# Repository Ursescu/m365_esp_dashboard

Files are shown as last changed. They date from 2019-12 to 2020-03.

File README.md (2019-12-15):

# M365 Dashboard replacement

## Description

Replacement for BLE m365 scooter dashboard using ESP32 chip.

## Build

Clone official esp-idf sdk repo and set `IDF_PATH` environment variable
to point it.

```bash
    git clone --recursive https://github.com/espressif/esp-idf.git ~/esp-idf

    cd ~/esp-idf && ./install.sh && . ./export.sh
```

Build app and watch the info using `make`.

```bash
    make flash monitor
```

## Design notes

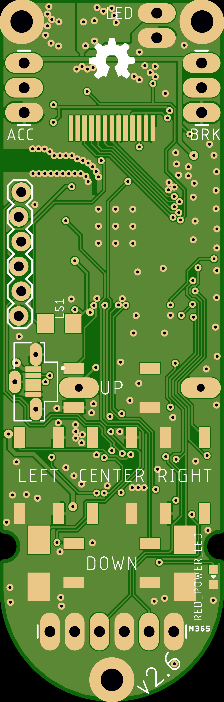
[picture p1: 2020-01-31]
pcb/pcb-render-dashboard-top.png

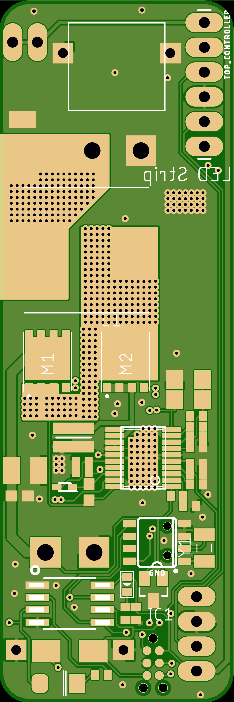
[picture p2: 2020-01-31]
pcb/pcb-render-led-source-top.png

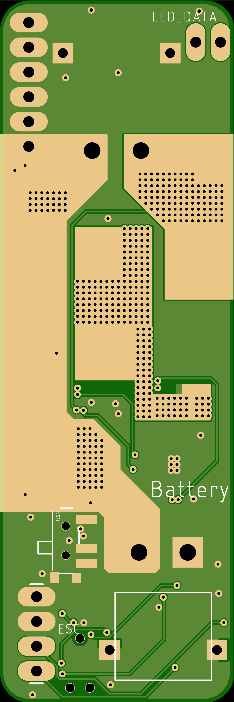
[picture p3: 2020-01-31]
pcb/pcb-render-led-source-bottom.png

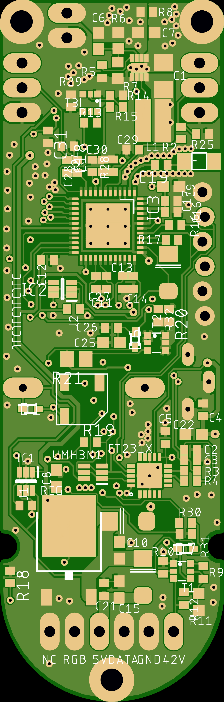
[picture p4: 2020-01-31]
pcb/pcb-render-dashboard-bottom.png

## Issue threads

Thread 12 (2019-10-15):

Add buzzer functionality

Ursescu, 2019-10-15:
Original XIOMI m365 scooter has a buzzer used to indicate alarm status received from ESC/BMS controller.

Add this feature to current implementation in `buzzer.c`.

- [ ]  Advanced beep function with frequency, on-off time and multiple beeps configuration.
- [ ]  Default beep configuration.

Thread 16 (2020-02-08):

Display UX&UI

rontav, 2020-02-08:
Here are some ideas for the display user interface:

### Main screen
| Guest/Eco | Normal | No limits |
| :-------------: | :-------------: |  :-------------: |
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 | 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 | 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

To change the info shown in the dashboard you can press the left or right keys. Proposed dashboard screens:
- summary (images shown above)
- detailed battery info
- max, average and current speed

###  Options screen
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
Is accessed by pressing the down key while on the Main screen. To get back to the Main screen, you have to press the up key while the top most option is highlighted.
Optionally, we could transition between the two screens with a simple translate animation.
The selected option should scroll back and forth to reveal the text.

The icons used are part of FontAwesome.

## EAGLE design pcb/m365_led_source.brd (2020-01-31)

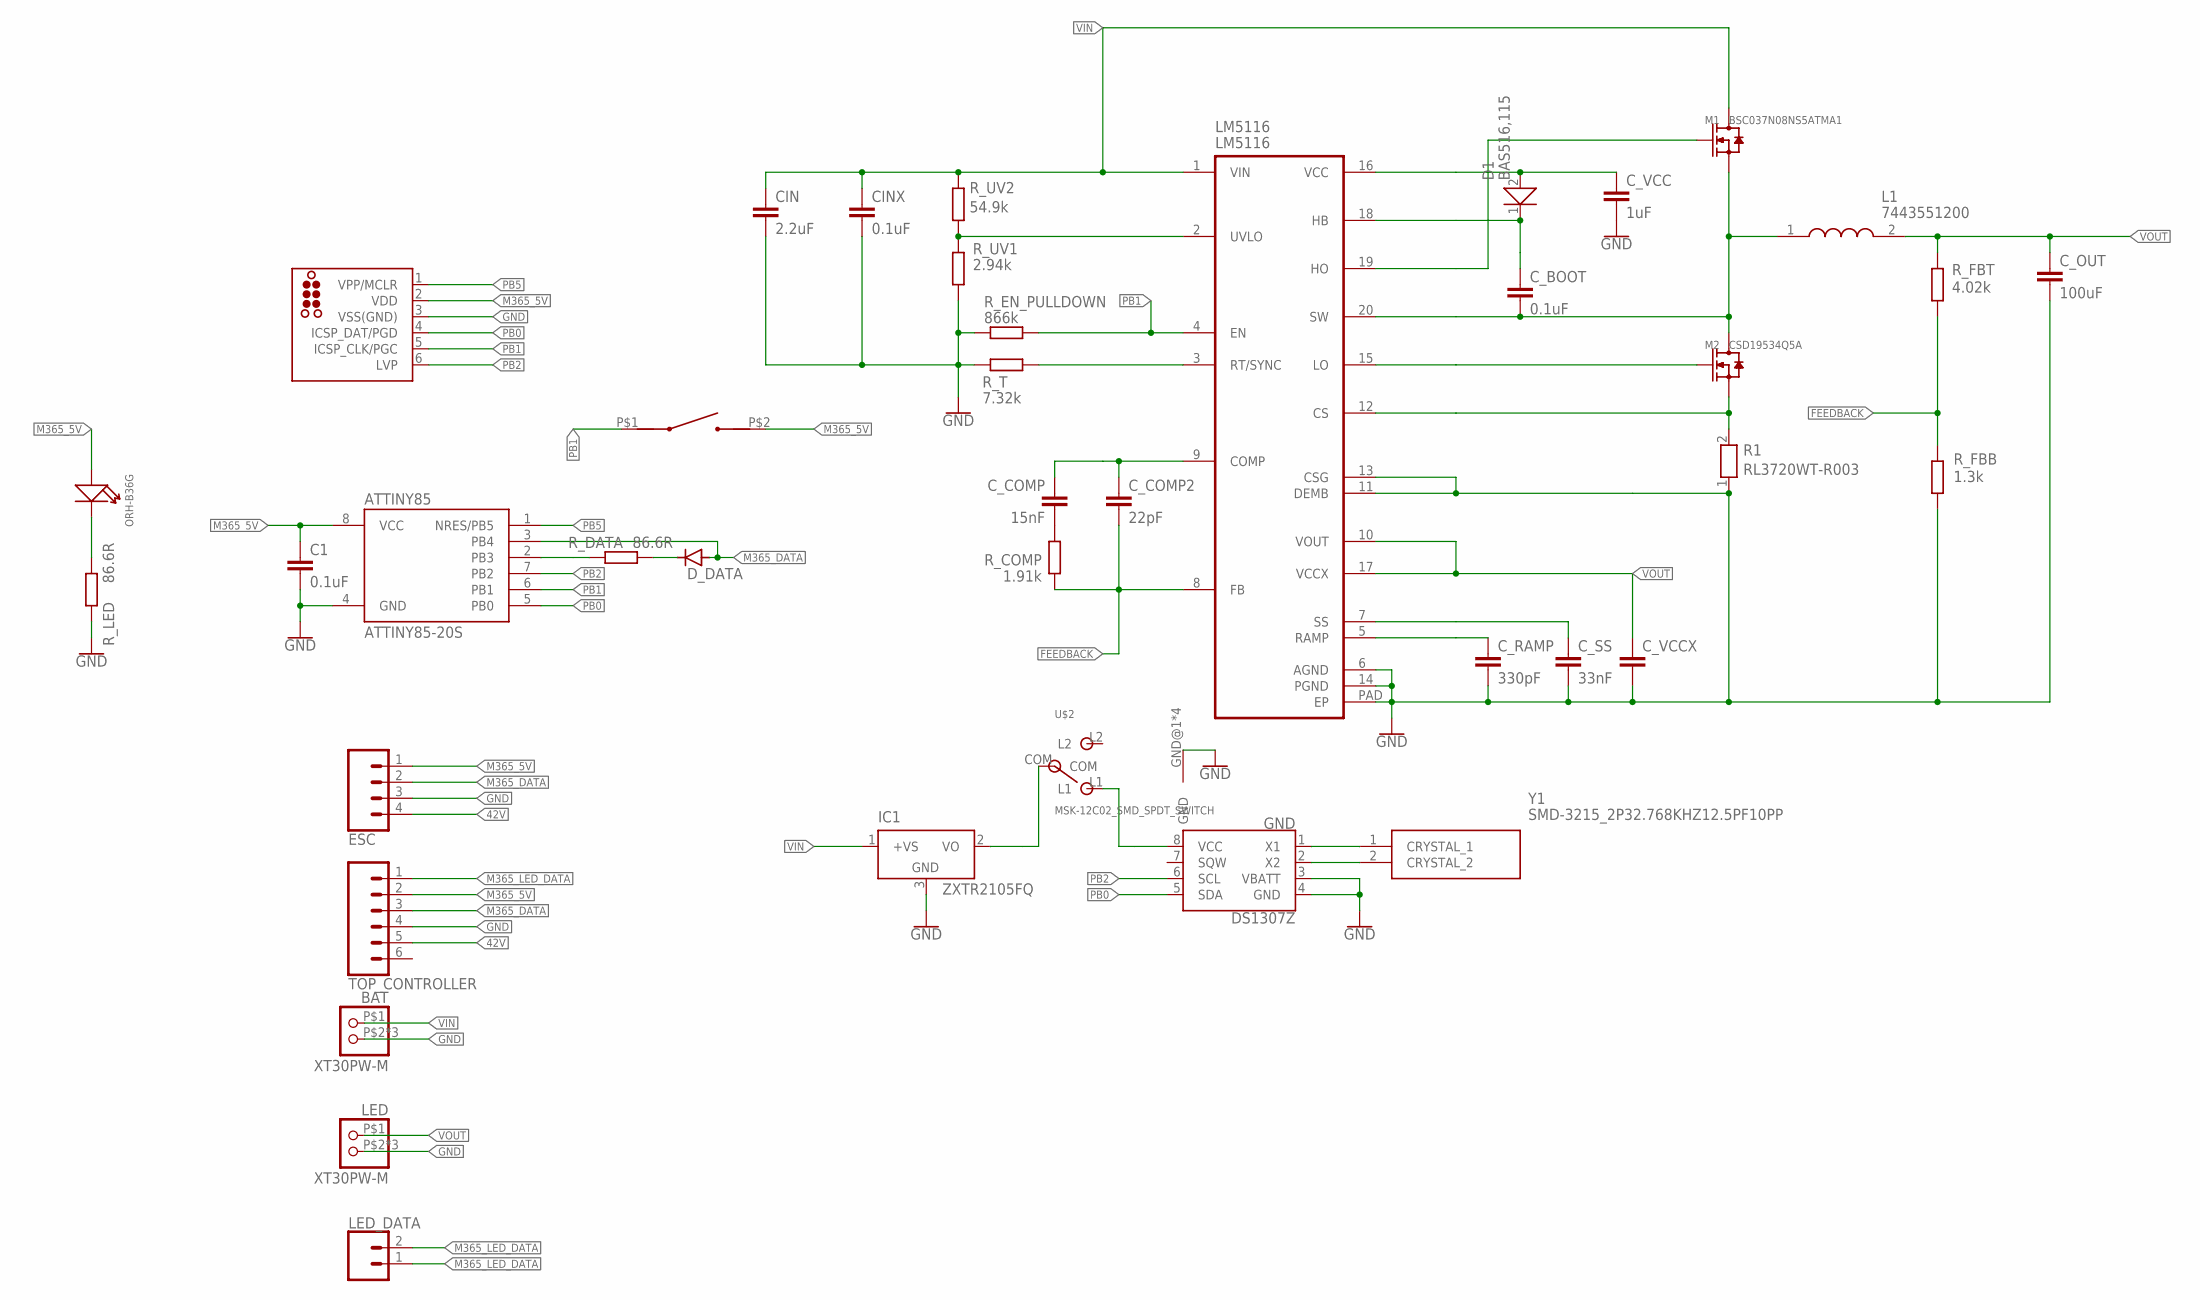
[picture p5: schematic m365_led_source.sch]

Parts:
ATTINY85: ATTINY85-20S; SOIC8_EIAJ_208MIL
BAT: XT30PW-M
C1: 0.1uF; C0402
CIN: 2.2uF; C1210
CINX: 0.1uF; C0603
C_BOOT: 0.1uF; C0603
C_COMP: 15nF; C1005
C_COMP2: 22pF; C0402
C_OUT: 100uF; C1210
C_RAMP: 330pF; C0402
C_SS: 33nF; C0402
C_VCC: 1uF; C0402
C_VCCX: CC0402; C0402
D1: BAS516,115; SOD1608X65N
D_DATA: SMAFJ75A
ESC: CONN_04LONGPADS; 1X04_LONGPADS
GND: DS1307Z; SO08-0.15
IC1: ZXTR2105FQ; SOT23
J2: TC2030-MCP-NL
L1: 7443551200; WE-HCI_1350/136523
LED: XT30PW-M
LED_DATA: CONN_02PTH3; 1X02_LONGPADS
LM5116: LM5116; TSSOP20-PAD
M1: BSC037N08NS5ATMA1; CSD19531Q5AT
M2: CSD19534Q5A; CSD19531Q5AT
R1: RL3720WT-R003; RESC2038X70N
R_COMP: 1.91k; R0402
R_DATA: 86.6R; R0402
R_EN_PULLDOWN: 866k; R0402
R_FBB: 1.3k; R1206
R_FBT: 4.02k; R1206
R_LED: 86.6R; R0402
R_T: 7.32k; R0402
R_UV1: 2.94k; R0402
R_UV2: 54.9k; R0402
TINY_LED: ORH-B36G; LED-0603
TOP_CONTROLLER: CONN_06LONGPADS; 1X06_LONGPADS
U$1: TL3302BF260QJ
U$2: MSK-12C02_SMD_SPDT_SWITCH; MSK-12C02
Y1: SMD-3215_2P32.768KHZ12.5PF10PP; SMD3215_2P32768KHZ125PF10PPM

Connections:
5V_REG: IC1.2 (VO), U$2.COM
42V: ESC.4, TOP_CONTROLLER.5
FEEDBACK: C_COMP2.2, LM5116.8 (FB), R_COMP.1, R_FBB.2, R_FBT.1
GND: ATTINY85.4 (GND), BAT.P$2 (2), BAT.P$3 (2), BAT.P$4 (2), C1.2, CIN.2, CINX.2, C_OUT.2, C_RAMP.2, C_SS.2, C_VCC.2, C_VCCX.2, ESC.3, GND.3 (VBATT), GND.4 (GND), IC1.3 (GND), J2.3 (VSS(GND)), LED.P$2 (2), LED.P$3 (2), LED.P$4 (2), LM5116.6 (AGND), LM5116.11 (DEMB), LM5116.13 (CSG), LM5116.14 (PGND), LM5116.PAD (EP), R1.1, R_EN_PULLDOWN.1, R_FBB.1, R_LED.1, R_T.1, R_UV1.1, TOP_CONTROLLER.4, U$2.GND@1 (GND), U$2.GND@2 (GND), U$2.GND@3 (GND), U$2.GND@4 (GND)
M365_5V: ATTINY85.8 (VCC), C1.1, ESC.1, J2.2 (VDD), TINY_LED.+, TOP_CONTROLLER.2, U$1.P$2
M365_DATA: ATTINY85.3 (PB4), D_DATA.P$2 (ANODE), ESC.2, TOP_CONTROLLER.3
M365_LED_DATA: LED_DATA.1, LED_DATA.2, TOP_CONTROLLER.1
unnamed: C_COMP.2, R_COMP.2
unnamed: LM5116.2 (UVLO), R_UV1.2, R_UV2.1
unnamed: GND.8 (VCC), U$2.L1
unnamed: LM5116.3 (RT/SYNC), R_T.2
unnamed: C_COMP.1, C_COMP2.1, LM5116.9 (COMP)
unnamed: GND.1 (X1), Y1.1 (CRYSTAL_1)
unnamed: C_SS.1, LM5116.7 (SS)
unnamed: C_RAMP.1, LM5116.5 (RAMP)
unnamed: R_LED.2, TINY_LED.-
unnamed: D_DATA.P$1 (CATHODE), R_DATA.2
unnamed: GND.2 (X2), Y1.2 (CRYSTAL_2)
unnamed: LM5116.12 (CS), M2.1 (S), M2.2 (S), M2.3 (S), R1.2
unnamed: LM5116.15 (LO), M2.4 (G)
unnamed: C_BOOT.2, L1.1, LM5116.20 (SW), M1.1 (S), M1.2 (S), M1.3 (S), M2.5 (D), M2.6 (D), M2.7 (D), M2.8 (D), M2.9 (D)
unnamed: LM5116.19 (HO), M1.4 (G)
unnamed: C_BOOT.1, D1.1, LM5116.18 (HB)
unnamed: C_VCC.1, D1.2, LM5116.16 (VCC)
PB0: ATTINY85.5 (PB0), GND.5 (SDA), J2.4 (ICSP_DAT/PGD)
PB1: ATTINY85.6 (PB1), J2.5 (ICSP_CLK/PGC), LM5116.4 (EN), R_EN_PULLDOWN.2, U$1.P$1
PB2: ATTINY85.7 (PB2), GND.6 (SCL), J2.6 (LVP)
PB3: ATTINY85.2 (PB3), R_DATA.1
PB5: ATTINY85.1 (NRES/PB5), J2.1 (VPP/MCLR)
VIN: BAT.P$1 (1), CIN.1, CINX.1, IC1.1 (+VS), LM5116.1 (VIN), M1.5 (D), M1.6 (D), M1.7 (D), M1.8 (D), M1.9 (D), R_UV2.2
VOUT: C_OUT.1, C_VCCX.1, L1.2, LED.P$1 (1), LM5116.10 (VOUT), LM5116.17 (VCCX), R_FBT.2

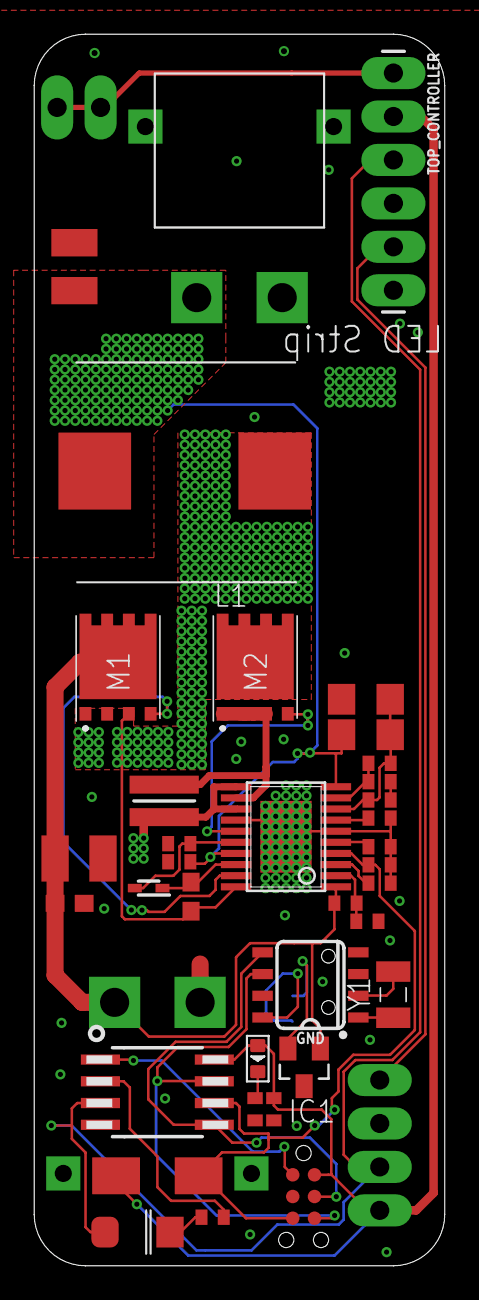
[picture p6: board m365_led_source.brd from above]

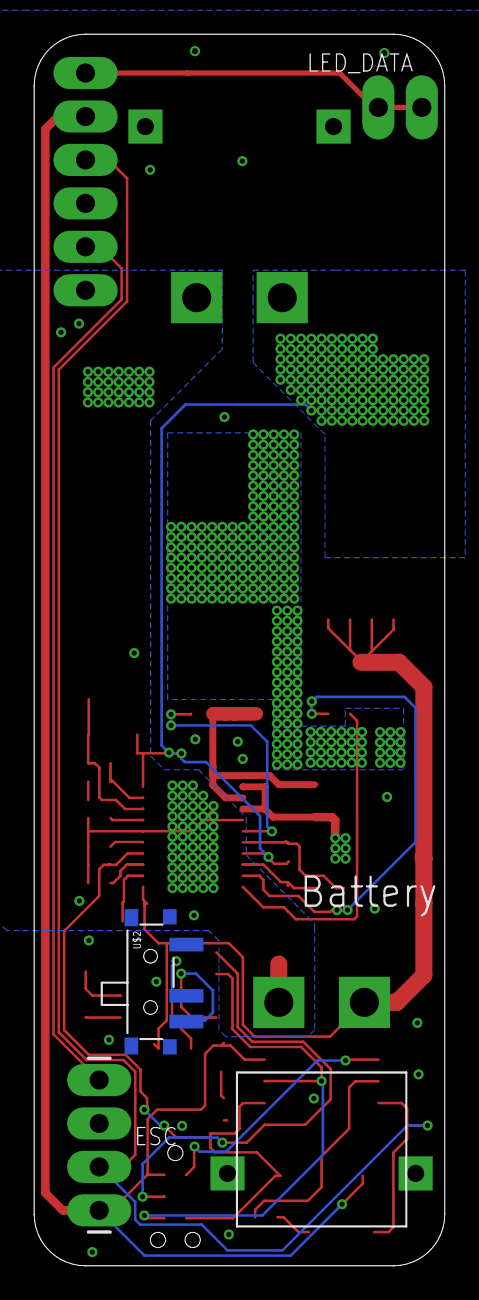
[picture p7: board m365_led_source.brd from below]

Board: 2 copper layers, 24.0 x 72.0 mm, 40 parts (4 on the bottom side), 31 nets.

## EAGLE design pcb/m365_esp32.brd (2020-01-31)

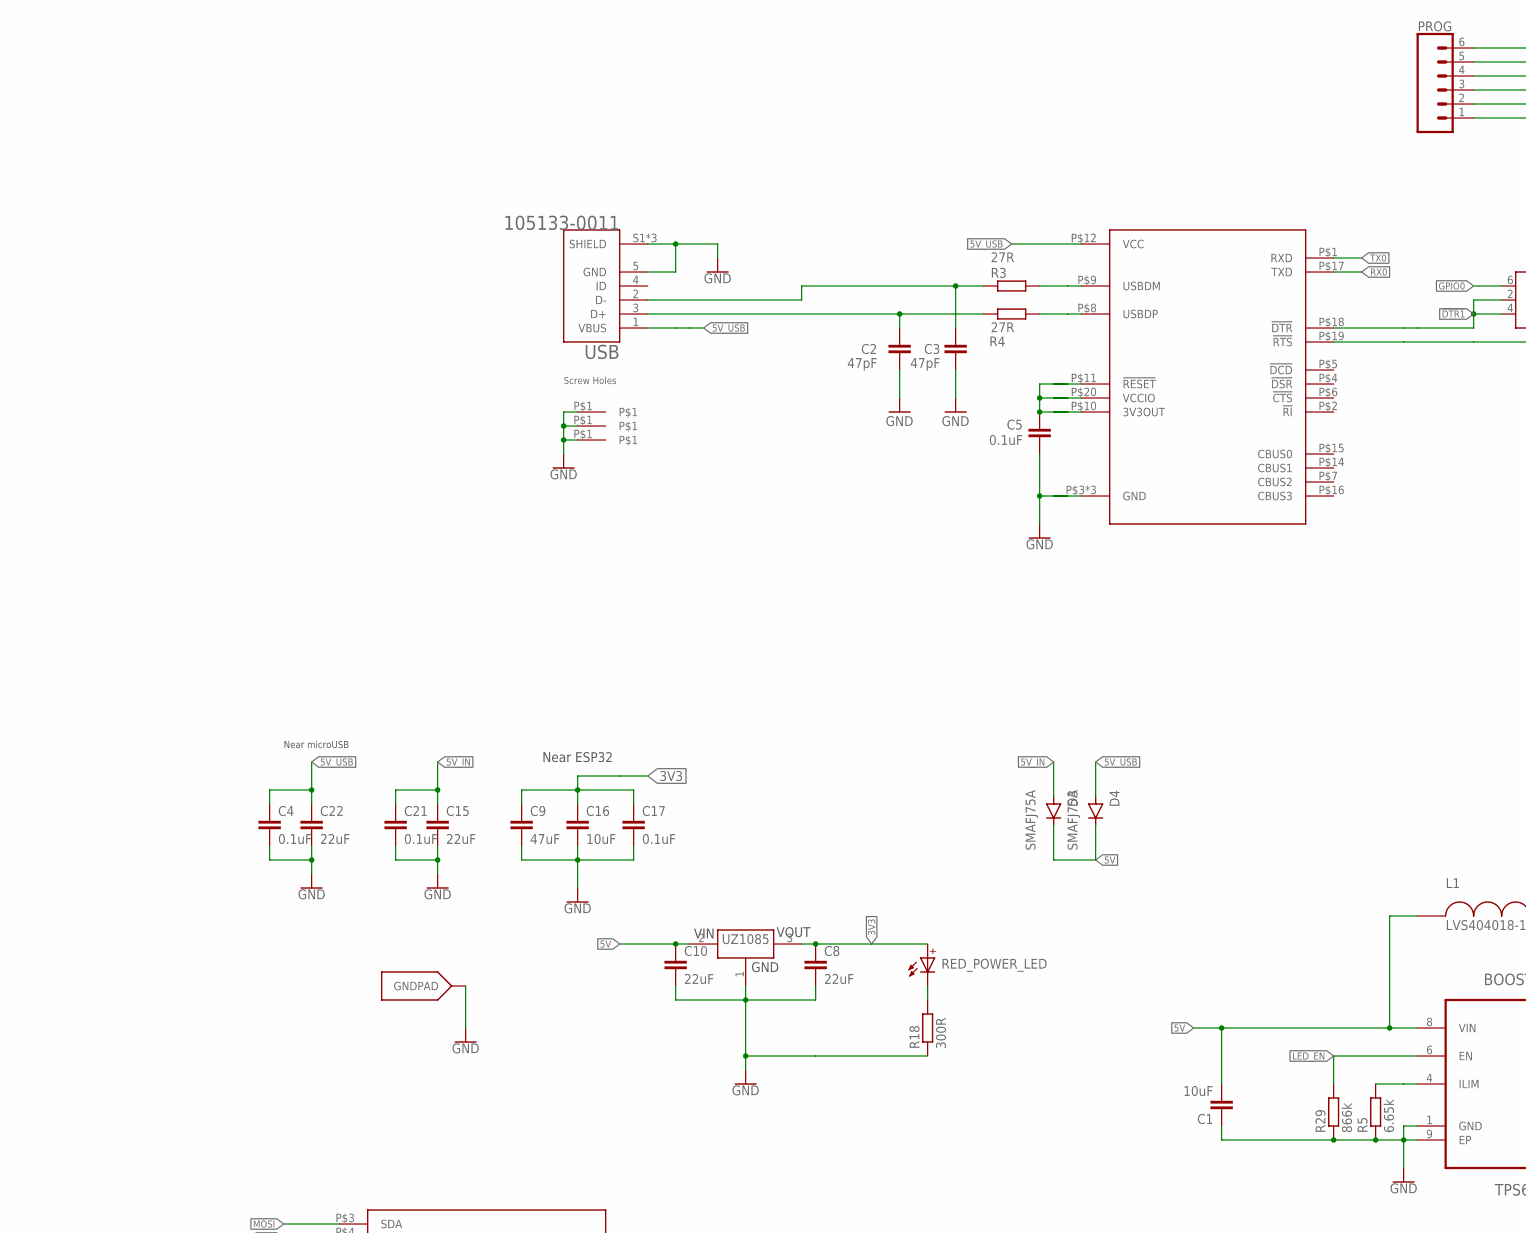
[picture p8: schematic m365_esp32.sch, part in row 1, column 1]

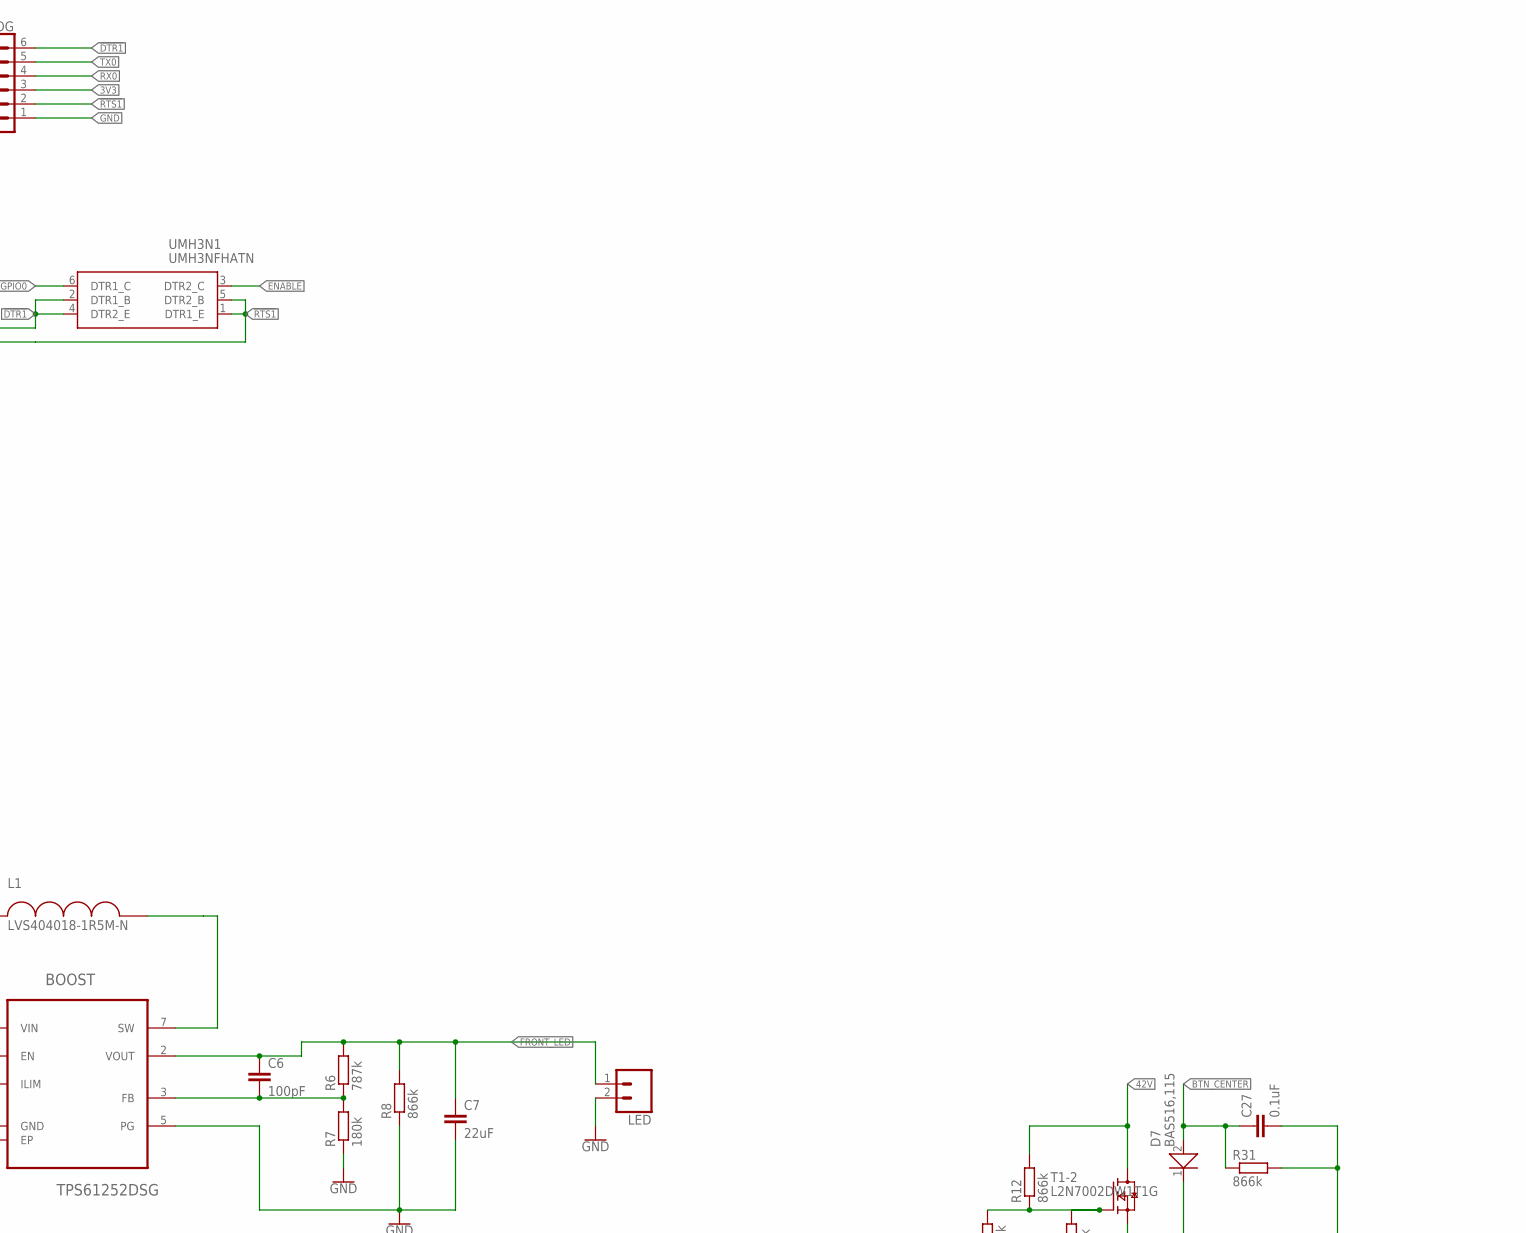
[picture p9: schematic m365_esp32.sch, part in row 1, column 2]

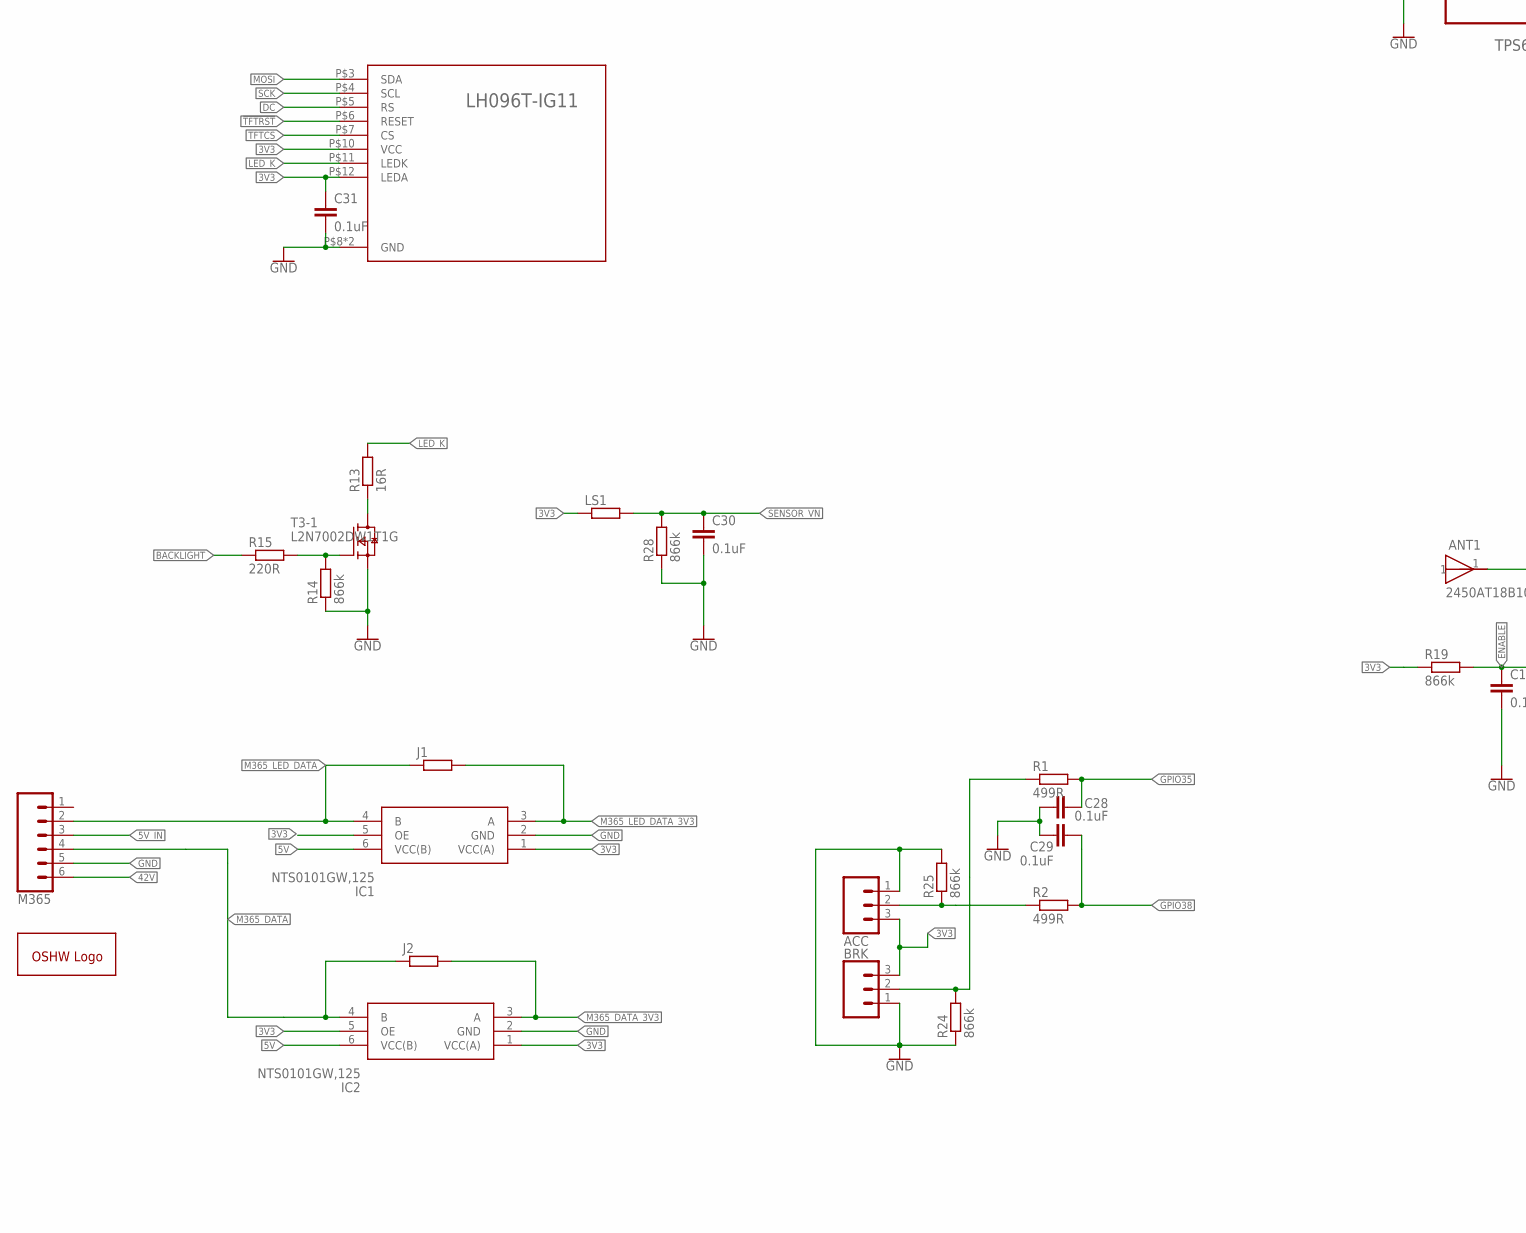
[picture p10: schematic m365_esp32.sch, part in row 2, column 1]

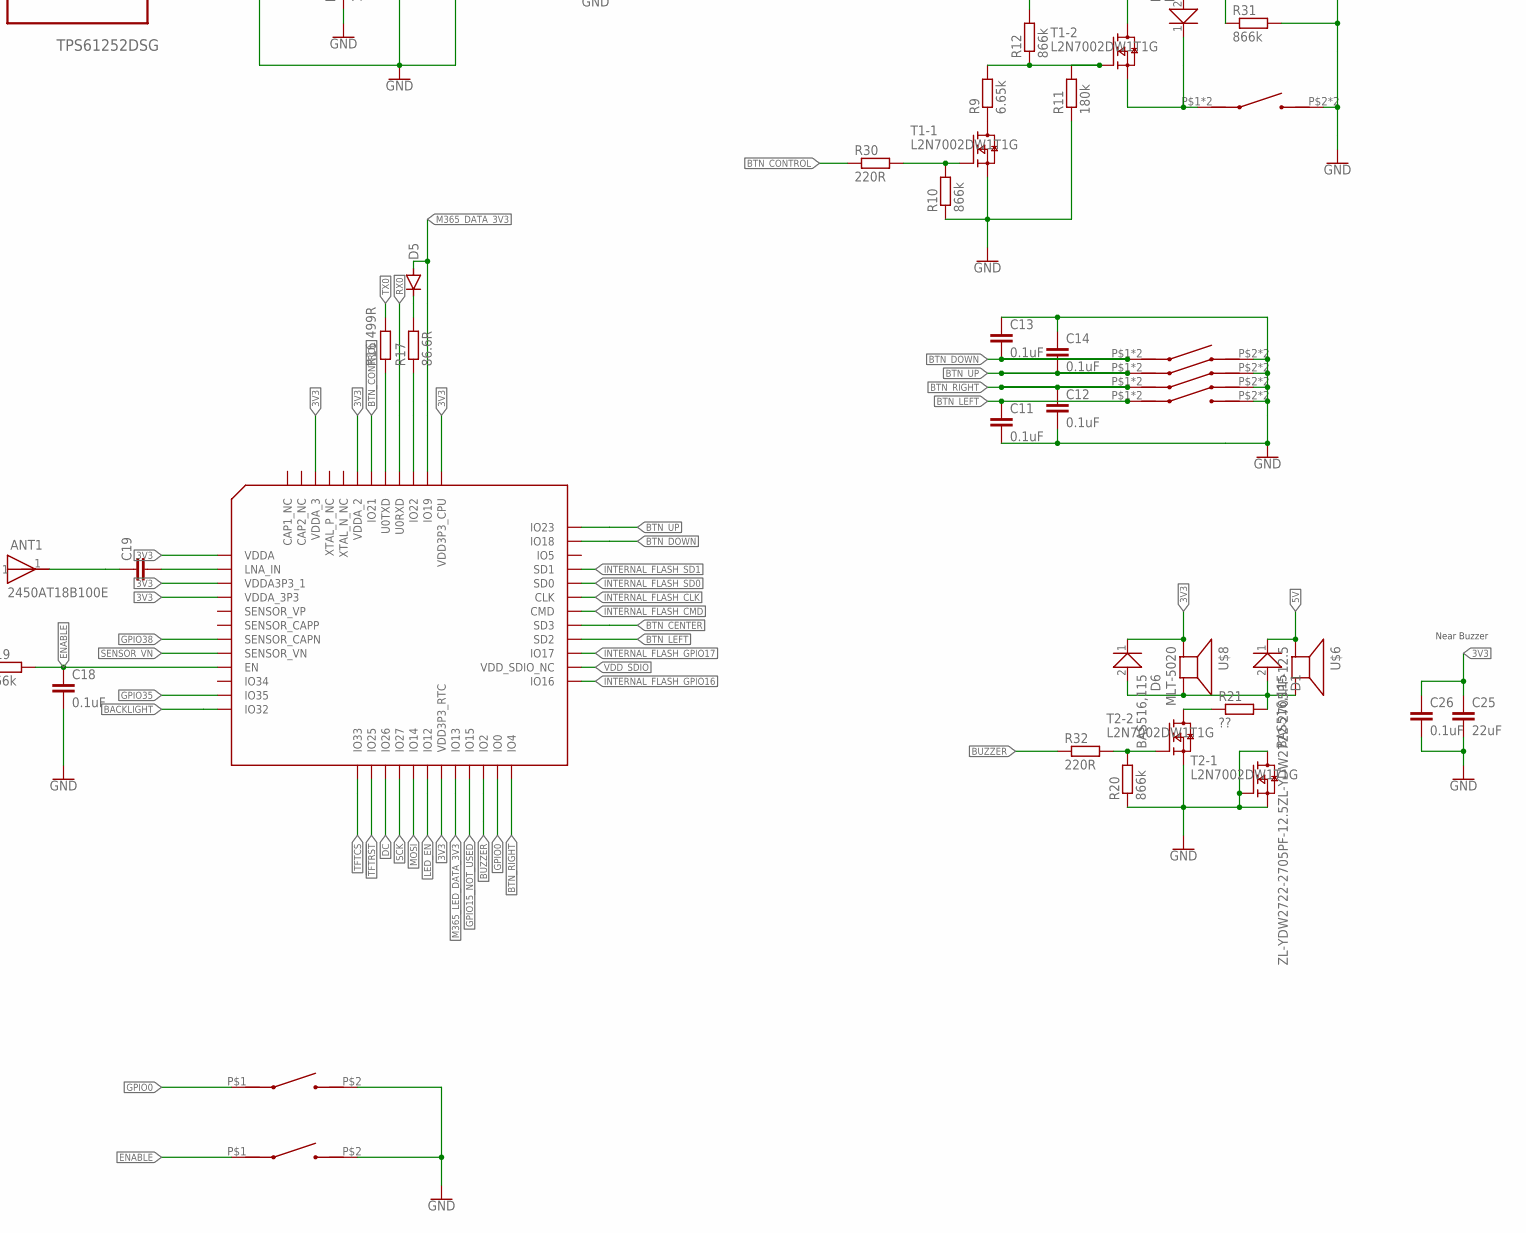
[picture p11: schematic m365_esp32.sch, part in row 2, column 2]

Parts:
ACC: CONN_03LONGPADS; 1X03_LONGPADS
ANT1: 2450AT18B100E; ANT_2450AT18B100E
BOOST: TPS61252DSG; SON50P200X200X80-9N
BRK: CONN_03LONGPADS; 1X03_LONGPADS
C1: 10uF; C1206
C2, C3: 47pF; C0402
C4, C5, C11, C12, C13, C14, C17, C18, C21, C26, C27, C28, C29, C30, C31: 0.1uF; C0402
C6: 100pF; C0603
C7, C8, C10, C15, C22, C25: 22uF; C0603
C9: 47uF; C0603
C16: 10uF; C0402
C19: CC0402; C0402
CENTER: KSEK43J
D1, D6, D7: BAS516,115; SOD1608X65N
D3, D4, D5: SMAFJ75A
DOWN: KSEK43J
FT231X: FT231XQ-R
GOLD_ORB_SM2: OSHWLOGOLOGO5MM; OSHW_5MM
IC1, IC2: NTS0101GW,125; SOT65P210X110-6N
IC3: UNEXPECTEDMAKER_ESP32-PICO-D4; UNEXPECTEDMAKER_PICO-D4-QFN48
J1, J2: RR0402; R0402
L1: LVS404018-1R5M-N; LVS404018
LED: CONN_02PTH3; 1X02_LONGPADS
LEFT: KSEK43J
LS1: RR1206; R1206
M365: CONN_06LONGPADS; 1X06_LONGPADS
PROG: CONN_06LOCK; 1X06_LOCK
R1, R2, R16: 499R; R0402
R3, R4: 27R; R0402
R5, R9: 6.65k; R0402
R6: 787k; R0603
R7, R11: 180k; R0603
R8, R10, R12, R14, R19, R20, R24, R25, R28, R29, R31: 866k; R0402
R13: 16R; R0402
R15, R30, R32: 220R; R0402
R17: 86.6R; R0402
R18: 300R; R0402
R21: ??; R0805
RED_POWER_LED: WL-SMCD_0603_150060BS55040; WL-SMCD_0603
REG: UZ1085L-33-TN3-R; TO-252-2
RIGHT: KSEK43J
T1, T2, T3: L2N7002DW1T1G; SOT363
U$1, U$2: TL3302BF260QJ
U$3, U$4, U$5: SCREWHOLE-M2
U$6: ZL-YDW2722-2705PF-12.5ZL-YDW2722-2705PF-12.5; ZL-YDW2722-2705PF-12.5
U$8: MLT-5020
U$11: LH096T-IG11
UMH3N1: UMH3NFHATN; SOT65P210X100-6N
UP: KSEK43J
USB: 105133-0011; MOLEX_105133-0011

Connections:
3V3: ACC.3, BRK.3, C8.1, C9.1, C16.1, C17.1, C25.1, C26.1, C31.1, D6.1, IC1.1 (VCC(A)), IC1.5 (OE), IC2.1 (VCC(A)), IC2.5 (OE), IC3.1 (VDDA), IC3.3 (VDDA3P3_1), IC3.4 (VDDA_3P3), IC3.19 (VDD3P3_RTC), IC3.37 (VDD3P3_CPU), IC3.43 (VDDA_2), IC3.46 (VDDA_3), LS1.1, PROG.3, R19.1, RED_POWER_LED.2 (A), REG.3 (VOUT), U$8.P$2 (+), U$11.P$10 (VCC), U$11.P$12 (LEDA)
5V: BOOST.8 (VIN), C1.2, C10.1, D1.1, D3.P$1 (CATHODE), D4.P$1 (CATHODE), IC1.6 (VCC(B)), IC2.6 (VCC(B)), L1.P$1, REG.2 (VIN), U$6.P$1 (+)
5V_IN: C15.1, C21.1, D3.P$2 (ANODE), M365.3
5V_USB: C4.1, C22.1, D4.P$2 (ANODE), FT231X.P$12 (VCC), USB.1 (VBUS)
42V: M365.6, R12.2, T1.3 (D)
!DTR1: FT231X.P$18 (!DTR), PROG.6, UMH3N1.2 (DTR1_B), UMH3N1.4 (DTR2_E)
!RTS1: FT231X.P$19 (!RTS), PROG.2, UMH3N1.1 (DTR1_E), UMH3N1.5 (DTR2_B)
!TFTRST: IC3.14 (IO25), U$11.P$6 (RESET)
A2: ACC.2, R2.1, R25.1
A5: BRK.2, R1.1, R24.2
BACKLIGHT: IC3.12 (IO32), R15.1
BTN_CENTER: C27.1, D7.2, IC3.29 (SD3), R31.1
BTN_CONTROL: IC3.42 (IO21), R30.1
BTN_DOWN: C13.2, DOWN.P$1, DOWN.P$4, IC3.35 (IO18)
BTN_LEFT: C11.1, IC3.28 (SD2), LEFT.P$1, LEFT.P$4
BTN_RIGHT: C12.1, IC3.24 (IO4), RIGHT.P$1, RIGHT.P$4
BTN_UP: C14.2, IC3.36 (IO23), UP.P$1, UP.P$4
BUZZER: IC3.22 (IO2), R32.1
DC: IC3.15 (IO26), U$11.P$5 (RS)
ENABLE: C18.1, IC3.9 (EN), R19.2, U$2.P$1, UMH3N1.3 (DTR2_C)
FRONT_LED: BOOST.2 (VOUT), C6.1, C7.1, LED.1, R6.2, R8.2
GND: ACC.1, BOOST.1 (GND), BOOST.5 (PG), BOOST.9 (EP), BRK.1, C1.1, C2.1, C3.1, C4.2, C5.2, C7.2, C8.2, C9.2, C10.2, C11.2, C12.2, C13.1, C14.1, C15.2, C16.2, C17.2, C18.2, C21.2, C22.2, C25.2, C26.2, C27.2, C28.1, C29.1, C30.2, C31.2, CENTER.P$2, CENTER.P$3, DOWN.P$2, DOWN.P$3, FT231X.P$3 (GND), FT231X.P$13 (GND), FT231X.P$21 (GND), IC1.2 (GND), IC2.2 (GND), IC3.EXP (GNDPAD), LED.2, LEFT.P$2, LEFT.P$3, M365.5, PROG.1, R5.1, R7.1, R8.1, R10.1, R11.1, R14.1, R18.1, R20.1, R24.1, R25.2, R28.1, R29.1, R31.2, REG.1 (GND), RIGHT.P$2, RIGHT.P$3, T1.1 (S), T2.1 (S), T2.2 (G), T2.4 (S), T2.6 (D), T3.1 (S), U$1.P$2, U$2.P$2, U$3.P$1, U$4.P$1, U$5.P$1, U$11.P$8 (GND), U$11.P$13 (GND), UP.P$2, UP.P$3, USB.5 (GND), USB.S1 (SHIELD), USB.S2 (SHIELD), USB.S3 (SHIELD)
GPIO0: IC3.23 (IO0), U$1.P$1, UMH3N1.6 (DTR1_C)
GPIO15_NOT_USED: IC3.21 (IO15)
GPIO35: C28.2, IC3.11 (IO35), R1.2
GPIO38: C29.2, IC3.7 (SENSOR_CAPN), R2.2
INTERNAL_FLASH_CLK: IC3.31 (CLK)
INTERNAL_FLASH_CMD: IC3.30 (CMD)
INTERNAL_FLASH_GPIO16: IC3.25 (IO16)
INTERNAL_FLASH_GPIO17: IC3.27 (IO17)
INTERNAL_FLASH_SD0: IC3.32 (SD0)
INTERNAL_FLASH_SD1: IC3.33 (SD1)
LED_EN: BOOST.6 (EN), IC3.18 (IO12), R29.2
LED_K: R13.2, U$11.P$11 (LEDK)
LNA_IN: C19.2, IC3.2 (LNA_IN)
M365_DATA: IC2.4 (B), J2.1, M365.4
M365_DATA_3V3: D5.P$2 (ANODE), IC2.3 (A), IC3.38 (IO19), J2.2
M365_LED_DATA: IC1.4 (B), J1.1, M365.2
M365_LED_DATA_3V3: IC1.3 (A), IC3.20 (IO13), J1.2
MOSI: IC3.17 (IO14), U$11.P$3 (SDA)
unnamed: IC3.41 (U0TXD), R16.1
unnamed: ANT1.1, C19.1
unnamed: R18.2, RED_POWER_LED.1 (C)
unnamed: CENTER.P$1, CENTER.P$4, D7.1, T1.4 (S)
unnamed: R9.2, R11.2, R12.1, T1.5 (G)
unnamed: C5.1, FT231X.P$10 (3V3OUT), FT231X.P$11 (!RESET), FT231X.P$20 (VCCIO)
unnamed: BOOST.7 (SW), L1.P$2
unnamed: BOOST.4 (ILIM), R5.2
unnamed: BOOST.3 (FB), C6.2, R6.1, R7.2
unnamed: R9.1, T1.6 (D)
unnamed: D1.2, D6.2, R21.2, U$6.P$2 (-), U$8.P$3 (-)
unnamed: R21.1, T2.3 (D)
unnamed: R13.1, T3.6 (D)
unnamed: R14.2, R15.2, T3.2 (G)
unnamed: D5.P$1 (CATHODE), R17.2
unnamed: IC3.39 (IO22), R17.1
unnamed: R10.2, R30.2, T1.2 (G)
unnamed: R20.2, R32.2, T2.5 (G)
RX0: FT231X.P$17 (TXD), IC3.40 (U0RXD), PROG.4
SCK: IC3.16 (IO27), U$11.P$4 (SCL)
SENSOR_VN: C30.1, IC3.8 (SENSOR_VN), LS1.2, R28.2
TFTCS: IC3.13 (IO33), U$11.P$7 (CS)
TX0: FT231X.P$1 (RXD), PROG.5, R16.2
USB-DATA_M: C3.2, R3.1, USB.2 (D-)
USB-DATA_P: C2.2, R4.1, USB.3 (D+)
USBDM: FT231X.P$9 (USBDM), R3.2
USBDP: FT231X.P$8 (USBDP), R4.2
VDD_SDIO: IC3.26 (VDD_SDIO_NC)

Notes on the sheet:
Near ESP32
Screw Holes
Near Buzzer
Near microUSB

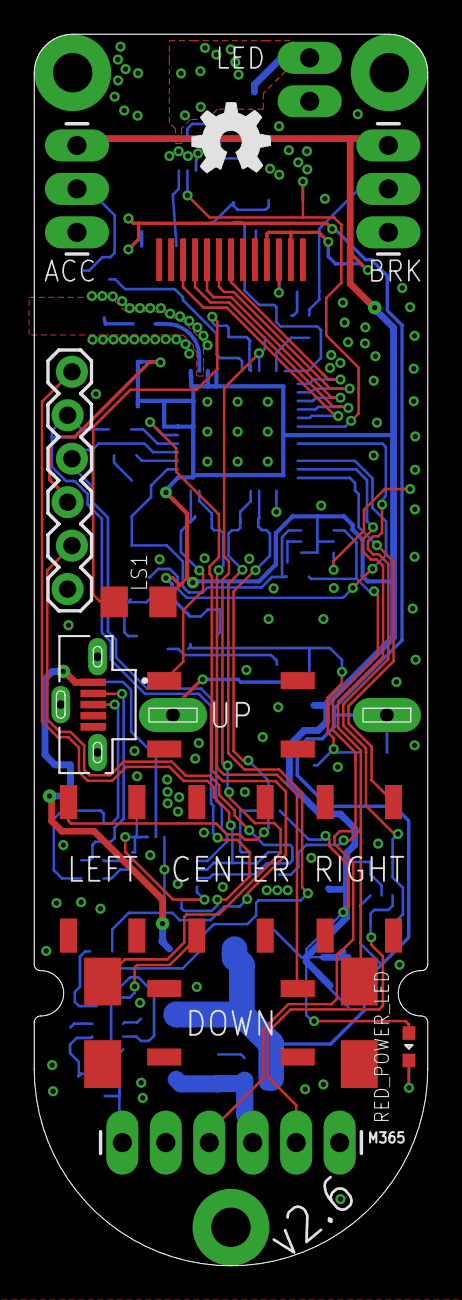
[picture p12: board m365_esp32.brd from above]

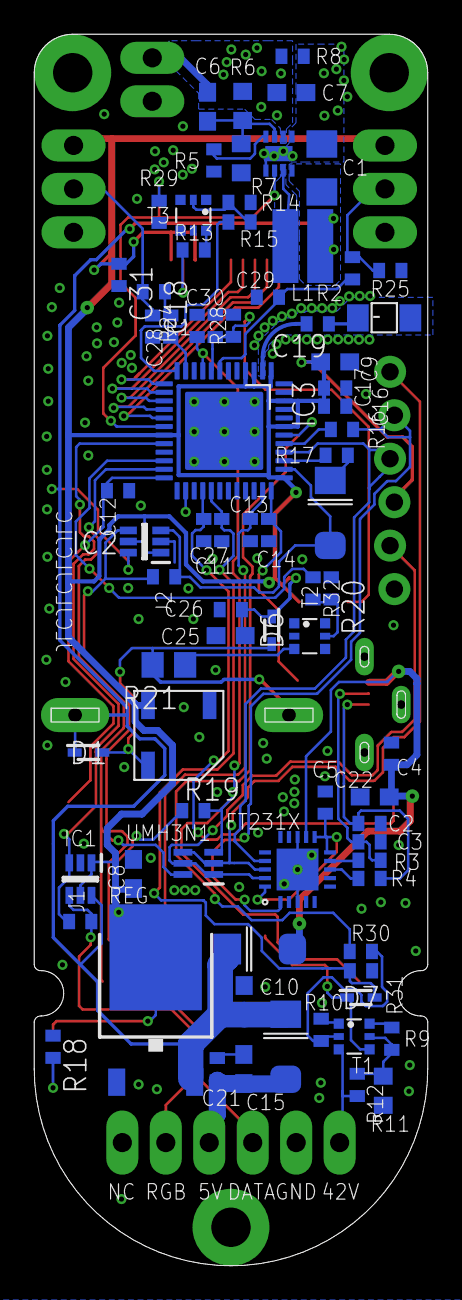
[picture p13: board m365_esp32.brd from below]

Board: 2 copper layers, 23.0 x 72.0 mm, 98 parts (77 on the bottom side), 60 nets.

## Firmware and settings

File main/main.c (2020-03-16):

/* 
 *Main file
 */
#include "freertos/FreeRTOS.h"
#include "freertos/portable.h"
#include "freertos/queue.h"
#include "freertos/semphr.h"
#include "freertos/task.h"
#include "freertos/timers.h"
#include "esp32/clk.h"
#include "esp_log.h"

#include "soc/rtc.h"
#include "soc/rtc_cntl_reg.h"

#include <stdio.h>
#include <string.h>

#define TAG "main"
#define PROCESS_CPU 0
#define COMM_CPU 1

#include "comm.h"
#include "buzzer.h"
#include "proto.h"
#include "display.h"
#include "utils.h"
#include "adc.h"
#include "preferences.h"
#include "wifi.h"
#include "fs.h"

/* Communication channel */
comm_chan uart_channel;

/* Sempahore to control the order of tasks */
SemaphoreHandle_t rx_sem = NULL;
SemaphoreHandle_t comm_sem = NULL;

static void tx_task(TimerHandle_t xTimer) {
    /* Tx task 
     * Send data at known time interval
     */

    if (uart_channel.tx_size > 0)
        comm_send(&uart_channel);

    /* Command written, now let the rx_task, wait for response */
    xSemaphoreGive(rx_sem);
}

static void rx_task() {
    /* Rx task
     * Listen for data after the tx is done
     */

    while (1) {
        /* Wait to receive signal from tx_task */
        xSemaphoreTake(rx_sem, portMAX_DELAY);

        /* Receive data from channel */
        comm_recv(&uart_channel);

        // print_command(uart_channel.rx, uart_channel.rx_size);

        /* Pass control to comm_task */
        xSemaphoreGive(comm_sem);
    }
}

static void comm_task() {
    /* Communication task
     * This is the place where the incoming commands are verified
     * and next command is set
     */

    while (1) {
        /* Wait to receive signal from rx_task */
        xSemaphoreTake(comm_sem, portMAX_DELAY);

        /*
         * Using half duplex UART will cause to read from the tx,
         * flushig UART Buffer seems to be too slow to clear the buffer before rx
         */

        /* Process command and prepare the sending command */
        proto_command(&uart_channel);

        /* Done processing command */
    }
}

static void display_task() {
    /* Dsiplay task
     * This will update the info from the BMS and ESC
     * The timing it's not that important for this task, update when
     * nothing else is doing work
     */

    display_init();

    while (1) {
        /* Get from queue and process it */

        /* data = queue get */

        display_refresh();
        /* update(data) */
    }
}

#define PIN_LED 25

static void wifi_task() {
    gpio_set_direction(PIN_LED, GPIO_MODE_OUTPUT);
    gpio_set_level(PIN_LED, 0);
    wifi_init();

    while (1) {
        gpio_set_level(PIN_LED, 1);
        vTaskDelay(100 / portTICK_PERIOD_MS);
        gpio_set_level(PIN_LED, 0);
    }
}

void app_main() {
    /* Esp-idf entry point */

    /* Debug, show frequency */
    rtc_cpu_freq_config_t old_config;
    rtc_clk_cpu_freq_get_config(&old_config);

    ESP_LOGI(TAG, "Main app, running freq %d", old_config.freq_mhz);
    ESP_LOGI(TAG, "Core id: %d", xPortGetCoreID());
    /* End debug */

    preferences_init();

    /* Init ADC */
    adc_init();

    /* Init Buzzer */
    buzzer_init();
    buzzer_default_beep();

    /* Init communication channel */
    comm_init();

    /* Init semaphores used to dictate the tasks */
    rx_sem = xSemaphoreCreateBinary();
    comm_sem = xSemaphoreCreateBinary();

    if (rx_sem == NULL || comm_sem == NULL) {
        /* Failed to init semaphore */
        ESP_LOGE(TAG, "Failed to create semaphores\n");
        while (1) {
            /* Spin forever */
        }
    }

    /* This is the main task to send data.
     * I need to be sure that command is prepared until next period. (20 ms)
     */
    int id = 1;
    TimerHandle_t tmr;

    tmr = xTimerCreate("tx_task", pdMS_TO_TICKS(TX_INTERVAL), pdTRUE, (void*)id, &tx_task);
    if (xTimerStart(tmr, 10) != pdPASS) {
        /* Failed to create timer task */
        ESP_LOGE(TAG, "Failed to create timer\n");
        while (1) {
            /* Spin forever */
        }
    }

    // processing is done on core 0
    xTaskCreatePinnedToCore(comm_task, "comm_task", 1024 * 4, NULL, configMAX_PRIORITIES, NULL, PROCESS_CPU);

    // // update the output on core 0
    xTaskCreatePinnedToCore(display_task, "disp_task", 1024 * 4, NULL, configMAX_PRIORITIES - 1, NULL, PROCESS_CPU);

    // rx is done on core 1
    xTaskCreatePinnedToCore(rx_task, "rx_task", 1024 * 4, NULL, configMAX_PRIORITIES, NULL, COMM_CPU);

    // xTaskCreatePinnedToCore(wifi_task, "wifi_task", 1024 * 4, NULL, configMAX_PRIORITIES, NULL, PROCESS_CPU);
}

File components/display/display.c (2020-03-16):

#include <time.h>
#include <stdio.h>
#include <stdlib.h>
#include <string.h>
#include "freertos/FreeRTOS.h"
#include "freertos/task.h"
#include <sys/stat.h>

#include "tftspi.h"
#include "tft.h"
#include "driver/gpio.h"

#include "display.h"
#include "proto.h"

#define TAG "display"

static time_t time_now, time_last = 0;

char velocityBuffer[10];

void display_refresh() {
    TFT_setFont(USER_FONT, TAHOMA);

    sprintf(velocityBuffer, "%.2f", proto_mainboard_stats.velocity * 1.60934);

    TFT_fillWindow(TFT_BLACK);
    TFT_print(velocityBuffer, 0, 8);

    sprintf(velocityBuffer, "%u", proto_mainboard_stats.battery);

    TFT_print(velocityBuffer, 0, 50);
    // TFT_bmp_image(0, 42, 0, RABBIT, NULL, 0);
    // TFT_bmp_image(0, 84, 0, SKULL, NULL, 0);
    // TFT_bmp_image(0, 126, 0, TURTLE, NULL, 0);

    vTaskDelay(300 / portTICK_PERIOD_MS);
}

void display_init() {
    esp_err_t ret;

    // === SET GLOBAL VARIABLES ==========================

    // ===================================================
    // ==== Set maximum spi clock for display read    ====
    //      operations, function 'find_rd_speed()'    ====
    //      can be used after display initialization  ====
    tft_max_rdclock = 1000000;
    // ===================================================

    // ====================================================================
    // === Pins MUST be initialized before SPI interface initialization ===
    // ====================================================================
    TFT_PinsInit();

    // ====  CONFIGURE SPI DEVICES(s)  ====================================================================================

    spi_lobo_device_handle_t spi;

    spi_lobo_bus_config_t buscfg = {
        .miso_io_num = PIN_NUM_MISO,  // set SPI MISO pin
        .mosi_io_num = PIN_NUM_MOSI,  // set SPI MOSI pin
        .sclk_io_num = PIN_NUM_CLK,   // set SPI CLK pin
        .quadwp_io_num = -1,
        .quadhd_io_num = -1,
        .max_transfer_sz = 6 * 1024,
    };
    spi_lobo_device_interface_config_t devcfg = {
        .clock_speed_hz = DEFAULT_SPI_CLOCK,  // Initial clock out at 8 MHz
        .mode = 0,                            // SPI mode 0
        .spics_io_num = -1,                   // we will use external CS pin
        .spics_ext_io_num = PIN_NUM_CS,       // external CS pin
        .flags = LB_SPI_DEVICE_HALFDUPLEX,    // ALWAYS SET  to HALF DUPLEX MODE!! for display spi
    };

    ret = spi_lobo_bus_add_device(SPI_BUS, &buscfg, &devcfg, &spi);
    assert(ret == ESP_OK);
    tft_disp_spi = spi;

    // ==== Test select/deselect ====
    ret = spi_lobo_device_select(spi, 1);
    assert(ret == ESP_OK);
    ret = spi_lobo_device_deselect(spi);
    assert(ret == ESP_OK);

    TFT_display_init();

    tft_font_rotate = 0;
    tft_text_wrap = 0;
    tft_font_transparent = 0;
    tft_font_forceFixed = 0;
    tft_gray_scale = 0;
    TFT_setGammaCurve(DEFAULT_GAMMA_CURVE);
    TFT_setRotation(PORTRAIT_FLIP);
    TFT_invertDisplay(INVERT_ON);
    TFT_setFont(DEFAULT_FONT, NULL);
    TFT_resetclipwin();
    TFT_fillWindow(TFT_BLACK);
}

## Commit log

2019-10-01 proto: Added stat structure that objectify the current state.
2019-10-02 FIX: proto: Now can read more commands from buffer. utils: Debug variable not used properly. adc: Dummy speed values to test the application comm: Relaxed TX_INTERVAL and RX_TIMEOUT Build errors.
    [adc.c, comm.h, main.c]
2019-10-13 Added first version of the pcb design
    [m365_esp32.brd, m365_esp32.sch]
2019-10-13 Added oshpark's pcb render
2019-10-13 Placed the buttons, center button multiplexer, usb interface, 3v3 regulator
    [m365_esp32.brd, m365_esp32.sch]
2019-10-14 Finished placing all components on the board
    [m365_esp32.brd, m365_esp32.sch]
2019-10-15 buzzer: Added function definitions for buzzer and integrated in proto.c
    [buzzer.c]
2019-11-25 Added secondary pcb to supply power for RGB led strip
    [m365_led_source.brd, m365_led_source.sch]
2019-11-25 Finished dashboard PCB
    [m365_esp32.brd, m365_esp32.sch]
2019-12-15 Added ESP32_TFT submodule
2019-12-16 Added basic adc reads
2019-12-16 Added acceleration and brake sensor Kconfig options
2019-12-16 Fixed ADC read
2019-12-16 Implemented acceleration&brake adc auto ranging
2020-01-31 Updated dashboard PCB design. Replaced ESP32-D0DW with ESP32-PicoD4 Added bigger buzzer footprint Removed RGB led
    [m365_esp32.brd, m365_esp32.sch]
2020-01-31 Updated led source board. Added RTC chip + regulator for it Changed the pinout of the attiny45 so that it can be programmed in place
    [m365_led_source.brd, m365_led_source.sch]
2020-03-02 Fixed ESP32_TFT submodule source URL.
2020-03-02 Fixed some typos, moved from printf to ESP_LOG.
    [main.c]
2020-03-16 Use ESP_LOG instead of printf
2020-03-16 Barebones sketch for attiny85 that tests the buck converter for the RGB LED strip.
2020-03-16 Modified sdkconfig to use custom PCB's GPIO
2020-03-16 Added spiffs support for bmp images
    [partitions.csv]
2020-03-16 Set SPI Flash size to 4MB
2020-03-16 Replace int variable declarations with uint8_t
    [adc.c]
2020-03-16 Added GPIO for front led and center button control
2020-03-16 Implemented barebones display of speed and battery stats
2020-03-16 Fix: rename display functions to adhere to naming convention
    [display.c, display.h]

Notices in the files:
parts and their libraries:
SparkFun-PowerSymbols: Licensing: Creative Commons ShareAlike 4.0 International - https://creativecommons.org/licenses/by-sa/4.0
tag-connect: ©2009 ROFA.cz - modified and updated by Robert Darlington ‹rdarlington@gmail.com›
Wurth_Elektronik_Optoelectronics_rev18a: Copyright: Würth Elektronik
